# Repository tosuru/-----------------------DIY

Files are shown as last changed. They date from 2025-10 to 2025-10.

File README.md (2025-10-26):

# ドブロマキシ 車中泊ベッド・スライド収納・スライドテーブルのDIY | CADデータ＋部品リスト

[関連情報：車中泊ベッド・スライド収納・スライドテーブルのDIY（フィアット ドブロ・K9）by oceans4 - みんカラ](https://minkara.carview.co.jp/userid/3643861/car/3600346/8404194/note.aspx)

本リポジトリは、個人的なDIYプロジェクトの「CADデータ＋部品リスト」を共有するものです。
対象はドブロマキシ（7人乗り）です。兄弟車にベルランゴロング、リフターロングがあります。

## 検討図：3D-CAD

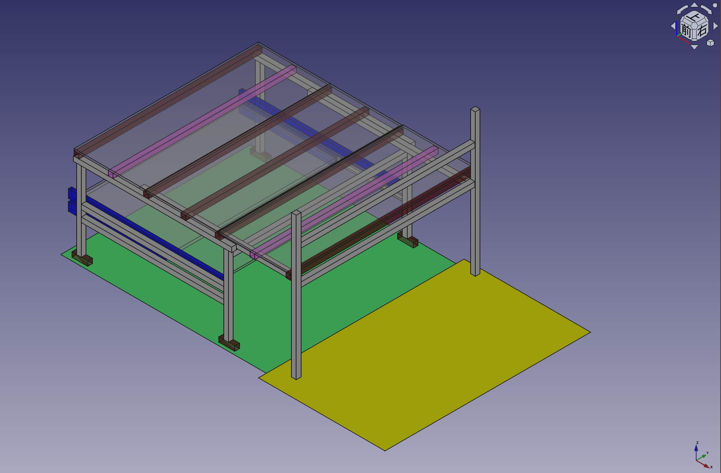
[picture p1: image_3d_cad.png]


[ドブロマキシ_車中泊仕様設計検討20240501.fcstd](ドブロマキシ_車中泊仕様設計検討20240501.fcstd)

※細かいジョイント金具などは反映されていません。

FreeCAD 0.21.2 で作成。以下から最新Verがダウンロード可能です。

[FreeCAD: Your own 3D parametric modeler](https://www.freecad.org/downloads.php)

## 部品リスト① フレーム関係

| 名称 | サイズ(mm) | 個数  | 備考 |
| --- | --- | --- | --- |
| アルミフレーム(黒) 1000mm | 30-30-1000 | 4 | |
| アルミフレーム(黒) 1100mm | 30-30-1100 | 3 | |
| アルミフレーム(黒) 500mm | 30-30-500  | 4 | |
| アルミフレーム(黒) 900mm | 30-30-900  | 6 | |
| ジョイント金具：スガツネ工業 (LAMP) ジョイントシステム PJ型 PJ-80AE | | 20  | メインフレーム用（脱着が容易なものを選定） |
| ジョイント金具：コーナーブラケット | | 4 | メインフレームの足用の木材固定用 |
| スライダS：エスユウエス(SUS) スライダS SFA-510 | | 4 | ベッドエクステンションフレームとメインフレームの接続部のスライド機構用 |
| スライダーTスロットナット M3 | | 4 | スライダS用 |
| M3×20 皿ボルト(十字穴 or 六角穴) | | 4 | スライダS用 |

## 部品リスト② スライド機構

|名称|サイズ(mm)|個数|備考|
|---|---|---|---|
|スライドレール ：ロック式 耐荷重 100kg レール 3段引き 長さ1000mm|1000-19-53|1セット|スライド収納用|
|スライドレール ：ロック式 耐荷重 100kg レール 3段引き 長さ600mm|600-19-53|1セット|スライドテーブル用|
|スライダーTスロットナット M5||１パック|スライドレール固定用、他|
|M5×10 皿ボルト(十字穴 or 六角穴)||１パック|スライドレール固定用、他|
|カラーアングル30型 900mm ブラック|30-30-900-2t|2|スライド収納用|
|カラーアングル30型 600mm ブラック|30-30-600-2t|2|スライドテーブル用|
|M5×10 皿ボルト＋M5ナット||14セット|200ピッチ程度に一か所固定(3x2+4x2=14)  <br>→M5のスライダーナットを流用し、スライド収納用の木材パネル側に片側４か所に切り欠きを作成|

## 部品リスト③ 木材、パネル関係

| 名称 | サイズ(mm) | 個数 | 備考 |
| --- | --- | ---- | --- |
| ランバーコアパネル12mm厚 (1820 × 910) | 1820-910-12t | 2 | ベッド、スライド収納 |
| パイン集成材パネル 18mm厚 (1820 × 600) | 1820-600-18t | 1 | スライドテーブル用 |
| 杉 角材 小割材 木材 1200×30×30mm 節なし | 30-30-1200 | 8 | ベッド用木材 |
| マグネットキャッチ 薄型(参考サイズ：41.5×16.5×1.9t) | | 4 | ベッド用木材 脱着式用 |
| オニメナット ツバ無し ねじ込み式 インサートナット M5×13 Eタイプ | | 2 | スライドテーブル用 |
| オニメナット ツバ無し ねじ込み式 インサートナット M4×10 Eタイプ | | 8 | スライド収納用、スライドテーブル用 |
| 六角ボルト M4×10 | | 8 | スライド収納用、スライドテーブル用  <br>→手持ちのM4の六角ボルトの頭のサイズが、カラーアングルのスロット穴の幅と同じ約7mmでピッタリ嵌ったため、これを簡易的な脱着式の接続部として使用。 |
| 手回しねじ　M5×12mm | | 2 | スライドテーブル用（外れ防止、念のため） |
| 水性ウレタンニス 0.7L | | 1~2  | テーブルを別色としたので2個準備。臭気と取扱いの容易性から水性を推奨。 |
| 木用ねじ（ブロンズ)3.8×32 | | １パック | |
| フェルトテープ | | 3 | エクステンションフレームの加重受け部の擦れ傷対策、木材パネルのガタガタ音対策などに多用 |

## カット寸法図（上記の購入済みをカット）

| 名称 | サイズ(mm) | 個数  | 備考 |
| --- | --- | --- | --- |
| ランバーコアパネル12mm厚 | 453-1165-12t | 3 | ベッド用 |
| ランバーコアパネル12mm厚 | 910-1055-12t | 1 | スライド収納 |
| パイン集成材パネル | 600-1055-18t | 1 | スライドテーブル用  |
| 杉 角材  30×30×100mm（100mm程度にカット） | 30-30-100 | 4 | メインフレームの足用 |
| 杉 角材  30×30×1160mm（40mmカット） | 30-30-1160 | 7 | 内、脱着式２式 |

## ホームセンターでのカット指示の例

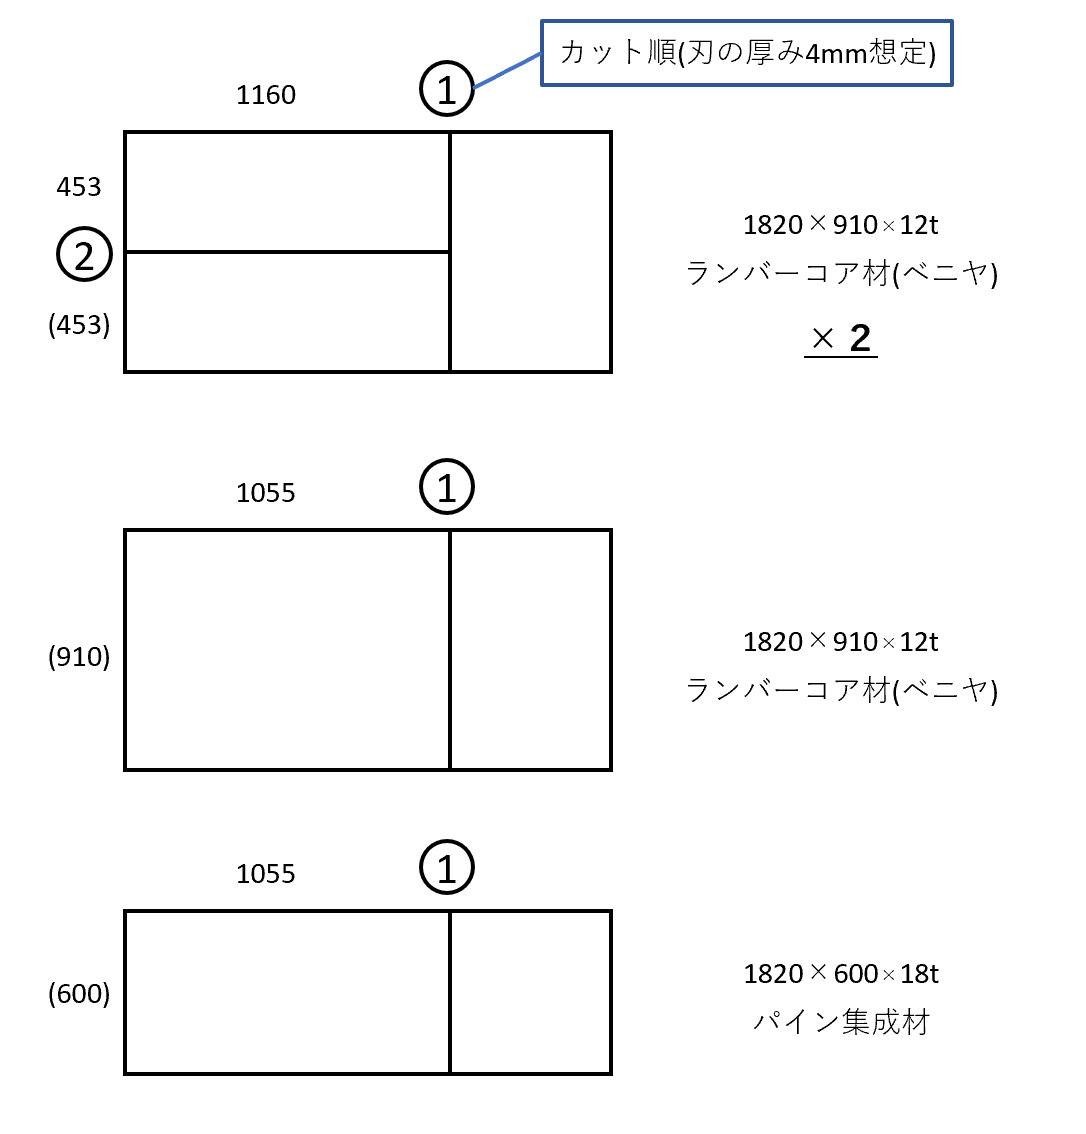
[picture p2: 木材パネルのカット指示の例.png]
木材パネルのカット指示の例


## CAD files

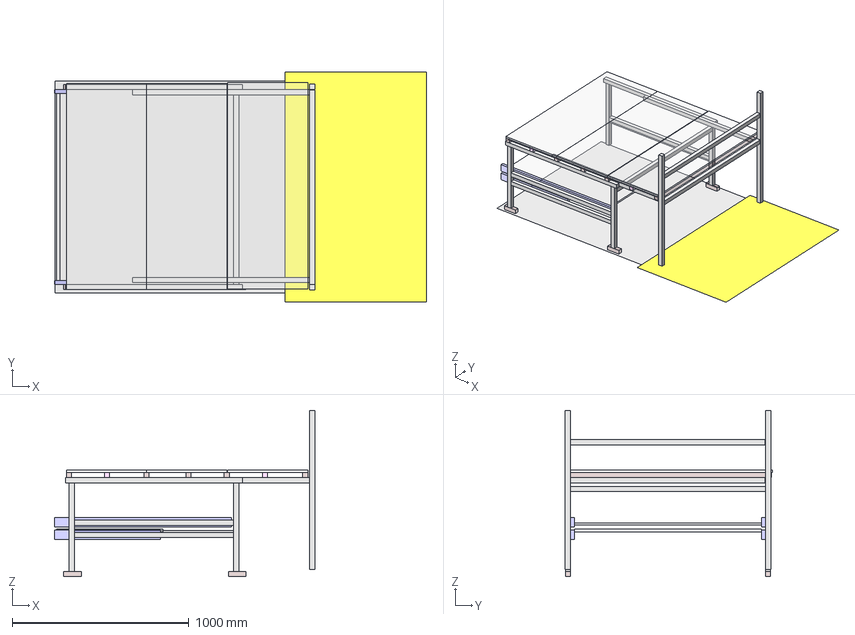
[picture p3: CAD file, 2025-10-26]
ドブロマキシ_車中泊仕様設計検討20240501.fcstd
2102.0 x 1300.0 x 940.0 mm
平面_荷室
平面_2ndシート収納状態
SF30 1000mm003
SF30 1000mm004
SF30 900mm003
SF30 900mm004
SF30 1100mm
SF30 1100mm001
ランバーコアパネル12㎜
wood flame 3030 1160mm 002
wood flame 3030 1160mm 003
wood flame 3030 1160mm 007
SF30 500mm003
SF30 500mm
SF30 500mm001
SF30 500mm002
SF30 900mm001
SF30 900mm002
SF30 1000mm001
SF30 1000mm002
SF30 900mm005
SF30 900mm006
wood flame 3030 100mm
wood flame 3030 100mm001
wood flame 3030 100mm002
wood flame 3030 100mm003
SF30 1100mm002
スライドレール+アングル 合計21mm
スライドレール+アングル 合計21mm001
ランバーコアパネル12mm
スライドレール+アングル 合計21mm002
スライドレール+アングル 合計21mm003
パイン集成材パネル
ランバーコアパネル12㎜003
wood flame 3030 1160mm 脱着式
wood flame 3030 1160mm 008
ランバーコアパネル001
wood flame 3030 1160mm 脱着式001
wood flame 3030 1160mm 010

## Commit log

2025-10-26 README.md タイトル修正
2025-10-26 イメージ画像を追加
